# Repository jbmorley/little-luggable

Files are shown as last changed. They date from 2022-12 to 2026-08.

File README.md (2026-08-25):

# Little Luggable



Raspberry Pi Cyberdeck

## Overview

The Little Luggable is my take on a cyberdeck. It's built around the [Raspberry Pi 5](https://www.raspberrypi.com/products/raspberry-pi-5/) and the [Pelican 1150 Protector Case](https://www.peli.com/eu/en/product/cases/protector/1150). It includes a [fully-custom mechanical keyboard](/docs/keyboard) designed to perfectly fit the lid of the 1150.

Check out the [project page](https://little-luggable.jbmorley.co.uk) for more.

# License

Little Luggable is Copyright (c) 2022-2026 Jason Morley (see [COPYRIGHT](https://github.com/jbmorley/little-luggable/blob/main/COPYRIGHT)) and licensed under the [Creative Commons Attribution 4.0 International License](https://creativecommons.org/licenses/by/4.0/) (see [LICENSE](https://github.com/jbmorley/little-luggable/blob/main/LICENSE)). Unless otherwise stated, photographs are Copyright (c) 2026 [Mar Mizunaka](http://marmizunaka.com), and cannot be reproduced without permission.

The Little Luggable depends on the following separately licensed third-party libraries and components:

- [Keebio Components](https://github.com/keebio/keebio-components), MIT License
- [Keebio-Parts.pretty](https://github.com/keebio/Keebio-Parts.pretty), MIT License
- [marbastlib](https://github.com/ebastler/marbastlib), CERN Open Hardware Licence Version 2 – Permissive
- [Nabla](https://fonts.google.com/specimen/Nabla), SIL Open Font License 1.1
- [Recursive](https://fonts.google.com/specimen/Recursive), SIL Open Font License 1.1
- [ZMK](https://github.com/zmkfirmware/zmk), MIT License

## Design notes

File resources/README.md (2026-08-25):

# Resources

## Acknowledgements

The resources in this directory have been added for convenience and future reference and copyright remains with their respective owners. They are not covered by the broader license of this repository.

- [**12mm Switch**, David Giangola, GrabCAD](https://grabcad.com/library/12mm-switch-1) – 12mm-switch-1.snapshot.2.zip
- [**Tactile Switches 6mm THT**, Dmitry Levin, GrabCAD](https://grabcad.com/library/tactile-switches-6mm-tht-1) – tactile-switches-6mm-tht-1.snapshot.2.zip

- [**Display OLED128x32**, Danilo Clemente, GrabCAD](https://grabcad.com/library/display-oled128x32-1) – display-oled128x32-1.snapshot.4.zip

- [**Nabla**, The Nabla Project Authors, Google Fonts](https://fonts.google.com/specimen/Nabla) – fonts/ (SIL Open Font License 1.1, see fonts/Nabla-OFL.txt)

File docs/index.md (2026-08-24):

---
layout: page
---

<div class="header">
    <div class="appname">{{ site.title }}</div>
    <div class="model">
        <model-viewer id="model" alt="A 3D model of the Little Luggable cyberdeck: a Raspberry Pi 5 and a custom mechanical keyboard built into a Pelican 1150 case" auto-rotate-delay="0" rotation-per-second="45deg" camera-controls interaction-prompt="none" orientation="0 0 225deg" camera-orbit="0deg 54.736deg auto" src="models/little-luggable.glb" poster="/images/poster.webp" shadow-intensity="1" high-performance="low-power" disable-zoom disable-tap>
            
            <noscript>
                A 3D render of the Little Luggable cyberdeck: a Raspberry Pi 5 and a custom mechanical keyboard built into a Pelican 1150 case
            </noscript>
        </model-viewer>
    </div>
    <div class="tagline">{{ site.description }}</div>
</div>
<script type="module" src="/assets/js/model-home.js"></script>

The Little Luggable is my take on a cyberdeck. Built around the [Raspberry Pi](https://www.raspberrypi.com/products/raspberry-pi-5/) and the [Pelican 1150 Protector Case](https://www.peli.com/eu/en/product/cases/protector/1150), it features a [fully-custom mechanical keyboard](/docs/keyboard) designed to perfectly fit the lid of the 1150.
{: .center}

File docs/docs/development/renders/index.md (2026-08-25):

---
title: Renders
---

Generating renders for the documentation:

1. Render using Fusion with a white, solid color background, and no ground plane
2. Trim the resulting image using [mogrify](https://imagemagick.org/script/mogrify.php):
   ```bash
   mogrify -trim -bordercolor white -border 60 render.png
   ```

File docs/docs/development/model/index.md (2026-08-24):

---
title: Model
priority: -100
---

The website uses [`<model-viewer>`](https://modelviewer.dev) to display a 3D model of the Little Luggable.

# Model

There are a number of steps to generate a suitable model:

1. Export from Fusion as a USDZ file.
2. Import the USDZ file into Blender.
3. Manually update the materials as Fusion does a terrible job when exporting materials.
    1. Create the materials in Blender by importing and running `scripts/blender-materials.py`.
    2. Select each element in-turn, delete the original material, and assign the correct new material.
4. Export the model as a GLB file.
5. Optimize the model:
   ```sh
   scripts/optimize-model.sh \
       exports/little-luggable.glb \
       docs/models/little-luggable.glb
   ```

> [!IMPORTANT]
>
> Do not check the un-optimized model in; it's massive.

# Poster

`<model-viewer>` supports a 'poster' which is displayed while the model is loading, or if JavaScript is disabled. This is generated using `<model-viewer>` itself to ensure it displays identically and the transition from poster to model is seamless.

1. Serve the site and open the front page:
   ```sh
   cd docs
   bundle install
   bundle exec jekyll serve --watch
   ```
2. Run in the console, and move the download into `docs/images/`:
   ```js
   const v = document.querySelector('#model');
   const blob = await v.toBlob({ idealAspect: true, mimeType: 'image/webp', qualityArgument: 0.85 });
   Object.assign(document.createElement('a'), {
       href: URL.createObjectURL(blob),
       download: 'poster.webp',
   }).click();
   ```
4. Reference it from the element: `poster="/images/poster.webp"`.

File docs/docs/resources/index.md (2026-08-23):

---
title: Resources
priority: -100
---

# Video Guides

- [Making a Keyboard Macropad PCB (Kicad 6.0), Noah Kiser](https://www.youtube.com/watch?v=7O8xGd7Pd88)
- [Single Button Nice!Nano Keyboard, Ben Vallack](https://www.youtube.com/watch?v=vr8LkjsRqZs)
- [Make your own analog keyboard PCB (in Kicad) - Part 1 (Schematic), riskable](https://www.youtube.com/watch?v=TfKz_FbZWLQ)

# Parts

  - [Broaching Standoff](https://www.youtube.com/watch?v=TuJRveLrtYI)
  - [Broaching nuts and standoffs](https://www.inserco.eu/en/broaching-inserts-ipcbricbfhiscbr/)
  - [Solderable threaded inserts?](https://www.designdevelopmenttoday.com/new-products/fastening-assembly/fastening-assembly/product/21092287/keystone-electronics-corp-zero-height-threaded-inserts-for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)
  - [Keyswitch Kicad Library](https://github.com/perigoso/keyswitch-kicad-library)

# 3D Models

- [Pelicane Case 1150, GrabCAD](https://grabcad.com/library/pelicane-case-1150-1)
- [USB 3 Type A Female Connector, Free3D](https://free3d.com/3d-model/usb-3-type-a-female-connector-9922.html)

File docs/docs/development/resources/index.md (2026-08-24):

---
title: Resources
priority: -100
---

# Video Guides

- [Making a Keyboard Macropad PCB (Kicad 6.0), Noah Kiser](https://www.youtube.com/watch?v=7O8xGd7Pd88)
- [Single Button Nice!Nano Keyboard, Ben Vallack](https://www.youtube.com/watch?v=vr8LkjsRqZs)
- [Make your own analog keyboard PCB (in Kicad) - Part 1 (Schematic), riskable](https://www.youtube.com/watch?v=TfKz_FbZWLQ)

# Manufacture

- [Recommended Tapping Drill and Clearance Hole Sizes](https://international.optimas.com/technical-resources/tapping-sizes/)

# Dimensions

- [Keystone cutout](https://www.phoenixcontact.com/en-pc/products/rj45-socket-insert-cuc-k-j1zni-s-r4idc8-1419021)

  

# Parts

  - [Broaching Standoff](https://www.youtube.com/watch?v=TuJRveLrtYI)
  - [Broaching nuts and standoffs](https://www.inserco.eu/en/broaching-inserts-ipcbricbfhiscbr/)
  - [Solderable threaded inserts?](https://www.designdevelopmenttoday.com/new-products/fastening-assembly/fastening-assembly/product/21092287/keystone-electronics-corp-zero-height-threaded-inserts-for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)
  - [Keyswitch Kicad Library](https://github.com/perigoso/keyswitch-kicad-library)

# 3D Models

- [Pelicane Case 1150, GrabCAD](https://grabcad.com/library/pelicane-case-1150-1)
- [USB 3 Type A Female Connector, Free3D](https://free3d.com/3d-model/usb-3-type-a-female-connector-9922.html)

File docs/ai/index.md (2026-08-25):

---
title: AI
---

# Generation

No AI was used in the creation of the Little Luggable hardware designs, and all photographs, images, and text used in the project, and on this website are human-authored.

Some AI tooling was used to generate support scripts for this website. This code has been reviewed thoroughly and its use is limited in scope. Source code created using AI is clearly marked and no copyright or license is asserted for these files.

## docs/assets/js/

- [`model-home.js`](https://github.com/jbmorley/little-luggable/blob/main/docs/assets/js/model-home.js)---JavaScript to animate the 3D model transition back to its home position

## scripts/

- [`blender-materials.py`](https://github.com/jbmorley/little-luggable/blob/main/scripts/blender-materials.py)---Python script to create Blender materials
- [`optimize-model.sh`](https://github.com/jbmorley/little-luggable/blob/main/scripts/optimize-model.sh)---Bash script calling `gltf-transform` to simplify GLB models
- [`recolor-nabla.py`](https://github.com/jbmorley/little-luggable/blob/main/scripts/recolor-nabla.py)---Python script to apply a color palettes to WOFF SVG fonts
- [`resize-images.sh`](https://github.com/jbmorley/little-luggable/blob/main/scripts/resize-images.sh)---Bash script to generate multiple sizes for images hosted on this website

# Tools

Little Luggable was created using [Autodesk Fusion](https://www.autodesk.com/trust/trusted-ai/ai-transparency-cards), on operating systems (macOS and Linux) known to be developed in part using AI. [Claude](https://claude.com) was used for research and as a search proxy.

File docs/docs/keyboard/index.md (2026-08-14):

---
title: Keyboard
---

The Little Keyboard is a custom 64-key keyboard that I created with the very specific goal of deviating as little as possible from a standard keyboard layout---it essentially doubles up the keys on the right-hand side of the keyboard by using the 'raise' modifier. Emoji keys are mapped using the 'lower' modifier, entered as unicode character codes using macros.



> [!TIP]
>
> This design was created using [Keyboard Layout Editor](http://www.keyboard-layout-editor.com) and the JSON can be found in the `keyboard` directory. It's best to use Chrome as, at the time of writing, PNG export doesn't work in Safari.

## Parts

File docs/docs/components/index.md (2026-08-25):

---
title: Components
---

The Little Luggable consists of two distinct components:

- [Compute](compute)---the Raspberry Pi, display, and UPS power board
- [Keyboard](keyboard)---the Bluetooth keyboard and battery

These both comprise a collection of 3D printed, milled, and laser-cut parts, as well as a number of off-the-shelf components.

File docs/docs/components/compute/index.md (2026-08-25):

---
title: Compute
priority: 90
---



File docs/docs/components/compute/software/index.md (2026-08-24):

---
title: Software
---

# Operating System

The Little Luggable uses a Raspberry Pi, so you can use any operating system compatible with this incredibly versatile device. Personally, I am currently using Ubuntu Resolute 26.04.

# RTC

The Raspberry Pi 5 supports a [rechargeable real-time clock battery](https://www.raspberrypi.com/products/rtc-battery/) which is crucial if you're going to use it in a battery powered device like the Little Luggable.

In order to ensure the battery recharges, you'll need to add the following to your `config.txt`:

```plaintext
dtparam=rtc_bbat_vchg=3000000
```

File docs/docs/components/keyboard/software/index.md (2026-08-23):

---
title: Software
priority: 90
---

## Shortcuts

### Bluetooth

The keyboard can be paired with multiple devices.

- **Lower + Esc 1, 2, 3, 4** – select Bluetooth device
- **Lower + F5** – clear the current Bluetooth pairing

### Symbols

The keyboard is designed to be as close to a regular staggered key layout as possible. Since it's narrower than a standard keyboard, symbols typically to the right of the keyboard share space with the right-side letters and are accessible using the **Raise** modifier.

### Emoji

Dedicated emoji keys (achieved by unicode modifier key sequence macros) are available under many letters using the **Lower** modifier. This is experimental and the mapping is likely to evolve over time (I'd like to find room for  🥹, 🤯, and 👍 at the very least).

- **QUERTY**
  - **Lower + Q** – 🤔
  - **Lower + W** – 🧐
  - **Lower + E** – 😬
  - **Lower + R** – 🥲
  - **Lower + T** – 🙃
  - **Lower + Y** – 🫠
  - **Lower + U** – 😭
  - **Lower + I** – 🥰
  - **Lower + O** – 😘
  - **Lower + P** – 🤗
- **ASDF**
  - **Lower + A** – 🤞
  - **Lower + S** – 👆
  - **Lower + D** – 👌
- **ZXCV**
  - **Lower + Z** – ❤️
  - **Lower + X** – 🎉
  - **Lower + C** – 👀

### Firmware Version

You can trigger a macro to type in the current firmware version and build number using **Lower + Raise + A**.

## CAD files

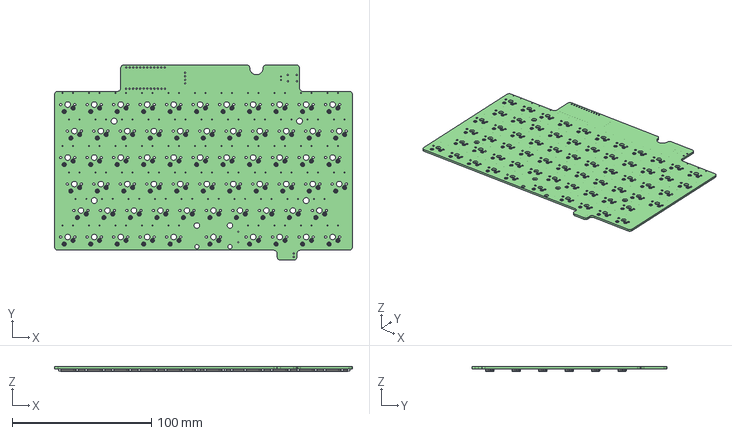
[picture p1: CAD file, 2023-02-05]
keyboard/keyboard.step
214.3 x 140.5 x 3.47 mm
keyboard PCB

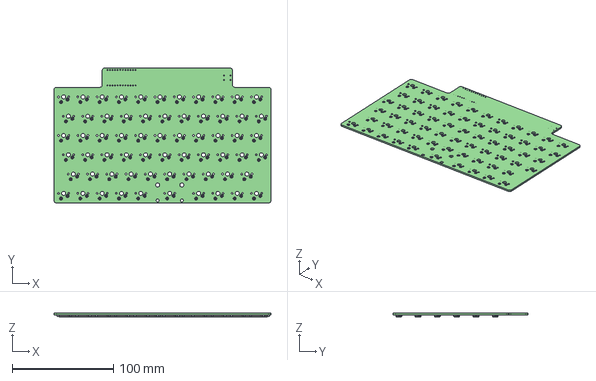
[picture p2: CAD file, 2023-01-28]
keyboard/pcb/keyboard.step
214.3 x 133.3 x 3.47 mm
keyboard PCB

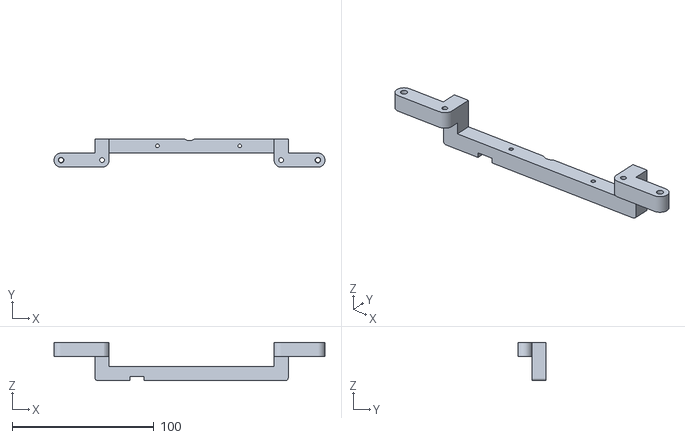
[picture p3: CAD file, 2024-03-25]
manufacture/bracket-top.stl
191.0 x 20.0 x 27.0

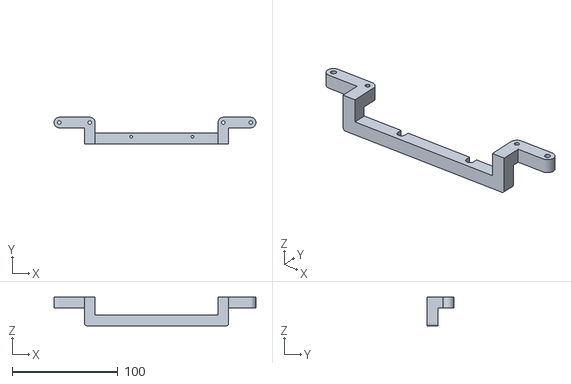
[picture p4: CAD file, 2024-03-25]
manufacture/bracket-bottom.stl
191.0 x 25.1 x 27.0

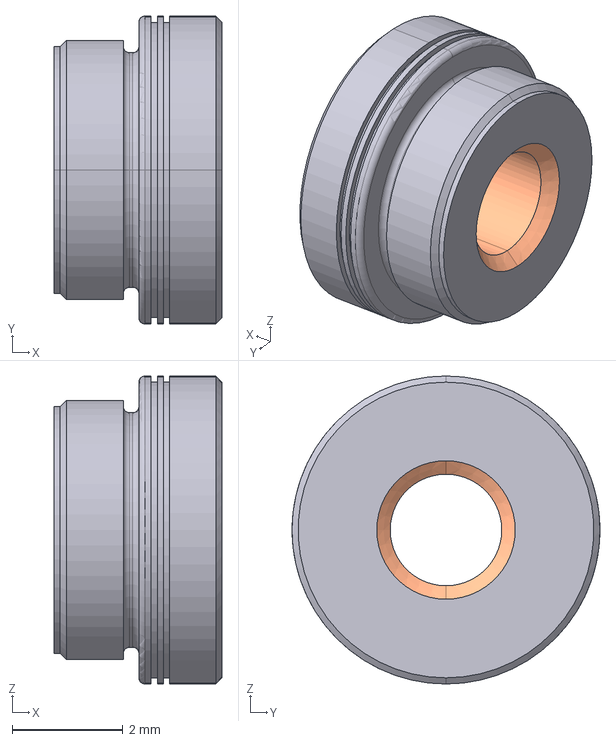
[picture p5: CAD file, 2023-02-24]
resources/KF2-M2.5-ET-Zygology-3D-02-05-2023.stp
3.03 x 5.56 x 5.56 mm

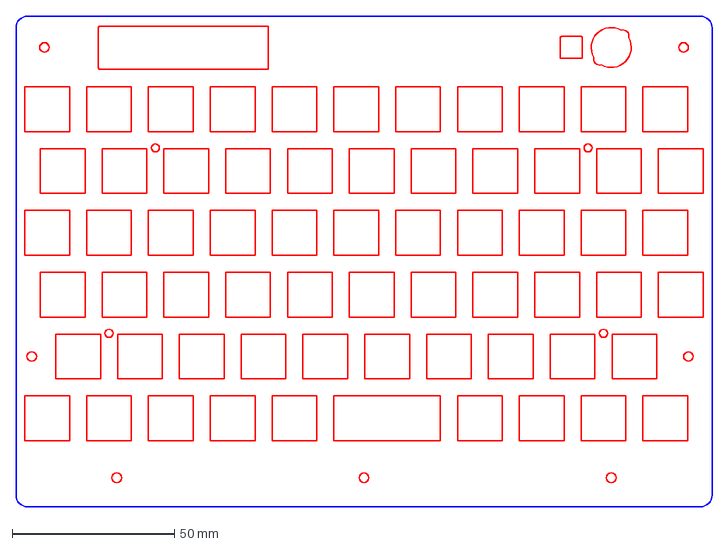
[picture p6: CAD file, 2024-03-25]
manufacture/keyboard-mounting-plate-kerf-adjusted-0.2.dxf
214.5 x 151.2 mm

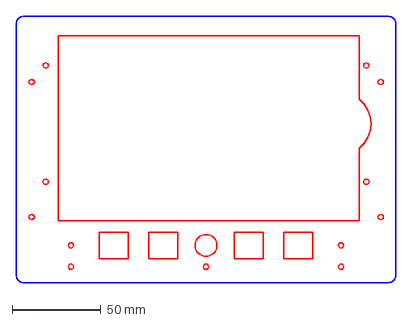
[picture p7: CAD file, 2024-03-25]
manufacture/screen-fascia-bottom-kerf-adjusted-0.2.dxf
214.2 x 150.2 mm

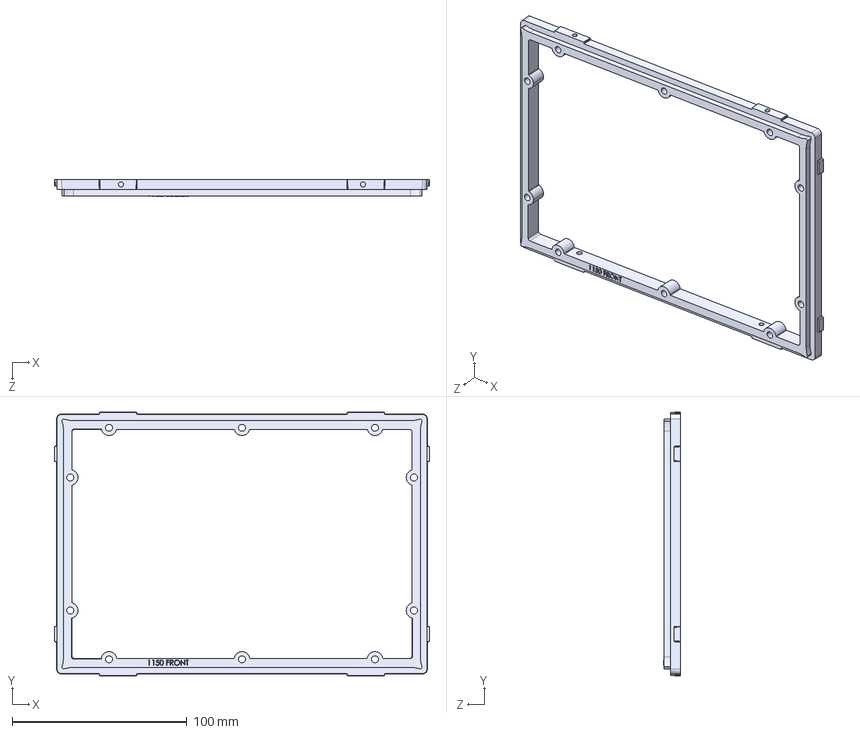
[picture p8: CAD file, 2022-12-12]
resources/1153-946-110.STEP
214.9 x 151.2 x 9.65 mm

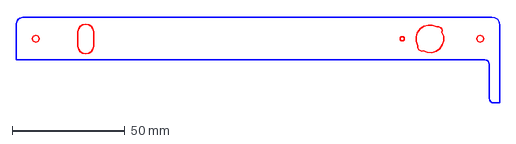
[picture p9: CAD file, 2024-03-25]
manufacture/keyboard-fascia-top-kerf-adjusted-0.2.dxf
214.5 x 38.1 mm

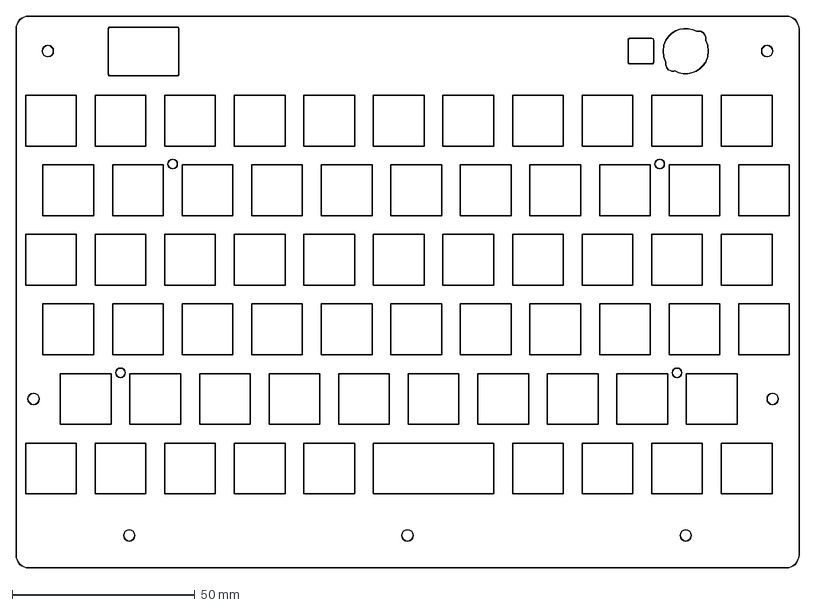
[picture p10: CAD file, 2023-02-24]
manufacture/keyboard-mounting-plate-kerf-adjusted-0.1.dxf
214.4 x 151.1 mm

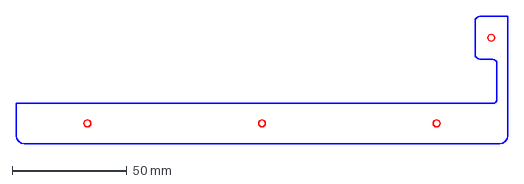
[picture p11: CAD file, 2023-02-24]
manufacture/keyboard-fascia-bottom-kerf-adjusted-0.2.dxf
214.5 x 55.7 mm

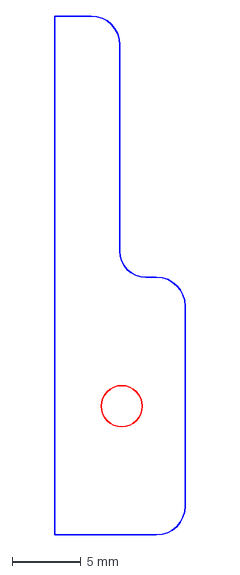
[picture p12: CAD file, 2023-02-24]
manufacture/keyboard-fascia-left-kerf-adjusted-0.2.dxf
9.50 x 37.8 mm

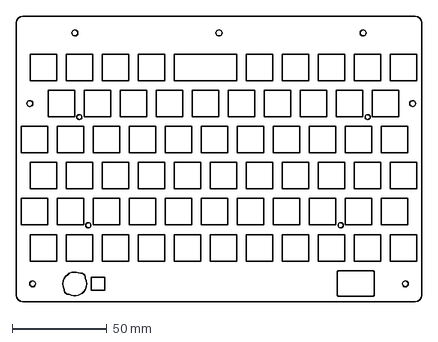
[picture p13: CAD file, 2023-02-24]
manufacture/keyboard-mounting-plate.dxf
214.3 x 151.0 mm

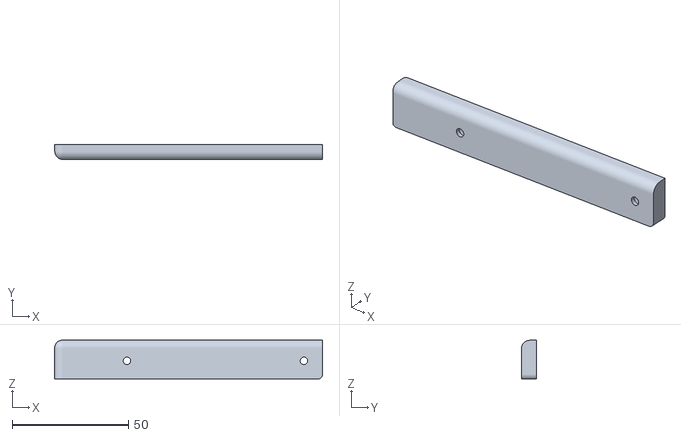
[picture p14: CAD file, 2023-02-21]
manufacture/keyboard-mounting-bracket-bottom-left.stl
115.4 x 6.47 x 16.8

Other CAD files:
manufacture/keyboard-switch-collar.stl
manufacture/keyboard-usb-port-collar.stl
manufacture/keyboard-mounting-bracket-bottom-right.stl
manufacture/screen-switch-collar.stl
manufacture/back.dxf
manufacture/keyboard-mounting-bracket-top-left.stl
manufacture/keyboard-mounting-bracket-top-right.stl
manufacture/keyboard-pcb.dxf
resources/91200A222_18-8 Stainless Steel Pan Head Slotted Screws.STEP
resources/93070A070_Alloy Steel Low-Profile Socket Head Screw.STEP

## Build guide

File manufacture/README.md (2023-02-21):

# Manufacture

## Settings

Settings for the [Makespace](https://makespace.org) laser cutters[^laser]:

[^laser]: These are for my own personal reference; you'll almost certainly want to do a few test cuts with your own laser cutter to dial in the correct settings.

- Jaws
  - 3mm acrylic
    - Speed = 10
    - Power = 85
    - Corner Power = 80

  - 1.5mm acrylic
    - Speed = 10
    - Power = 55
    - Corner Power = 55

- Betsy
  - 3mm acrylic
    - Speed = 10
    - Power = 90
    - Corner Power = 85

  - 1.5mm acrylic
    - Speed = 10
    - Power = 55
    - Corner Power = 55

N.B. When cutting 1.5mm acrylic, the kerfing[^kerf] seems to be about 0.2mm so dimensions need to be adjusted for high-tolerance parts like the keyboard mounting plate. For example, I found I needed to adjust the 14mm key-switch cutouts to be **13.8mm** to ensure the switches clip securely in place. I'm using the [DXF for Laser](https://apps.autodesk.com/FUSION/en/Detail/Index?id=7634902334100976871&appLang=en&os=Win64&autostart=true) plugin for Fusion 360 to automatically export kerf-adjusted parts.

[^kerf]: I'm measuring kerfing as the full width of the cut, meaning a 0.2mm kerf will shrink parts on each side of a cut by 0.1mm. I believe this is the correct definition of 'kerf' but wanted to clarify just in case my understanding was incorrect.

## Exports

Export as DXF using Adobe Illustrator for AutoCAD 2018:

Screenshot of Adobe Illustrator DXF export dialog

## Changes

### v1

### v2

### v3

- Add the power socket to the fascia and mounting bracket

### v4

- Initial prototype of the keyboard fascia and mounting plate

### v5

- Update the keyboard fascia to wrap around the keys
- Add power switch, reset switch, and USB-C port to the keyboard fascia
- Add mounting holes to the keyboard mounting plate
- Add collar for the keyboard latching switch
- Add keyboard PCB silhouette for fit testing

### v6

- Update the keyboard PCB silhouette to reposition the nice!nano and include the holes for the broaching nuts, and through-holes for the battery and power switch

### v7

- Update the keyboard fascia and mounting plate to [exactly] match the new PCB
- Add the keyboard mounting brackets

### v8

- Increase the M3 and M2.5 hole sizes across the screen and keyboard components (to 3.2mm and 2.7mm respectively)
- Increase the switch cutout diameter from 12mm to 12.5mm
- Increase the switch collar inner diameter to 12.25 and export an STL file for 3D printing
  - Add a screen switch collar (identical to the keyboard switch collar)
- Add a collar for the 90 degree keyboard USB-C port
- Update the bottom-left and bottom-right keyboard mounting brackets to actually centre the mounting holes on the case (and not the bottom row of keys)
- Add 0.2mm kerf-adjusted exports of the keyboard fascias and mounting plate

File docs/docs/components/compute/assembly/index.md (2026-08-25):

---
title: Assembly
priority: 90
---

# Parts

## Off-The-Shelf

| **Part** | **Quantity** |
| --- | --- |
| [Raspberry Pi 4 Model B](https://www.raspberrypi.com/products/raspberry-pi-4-model-b/) | 1 |
| [Raspberry Pi Touch Display](https://www.raspberrypi.com/products/raspberry-pi-touch-display/) | 1 |
| [PiJuice HAT](https://uk.pi-supply.com/products/pijuice-standard) | 1 |
| [PiJuice 12000mAh Battery](https://uk.pi-supply.com/products/pijuice-12000mah-battery) | 1 |
| [Pelican 1150 Protector Case](https://peliproducts.co.uk/products/1150-protector-case) | 1 |
| [Pelican 1150 Panel Frame](https://peliproducts.co.uk/products/1150-panel-frame) | 1 |
| [M3 Washer](https://www.amazon.co.uk/3mm-Flat-Washer-Form-Stainless/dp/B08TDPSBBY) | 4 |
| [M3 Spacer, 3mm](https://www.amazon.co.uk/dp/B0BHJP3KJP) | 6 |
| [Raspberry Pi Standoff Set, 11mm](https://thepihut.com/products/raspberry-pi-standoff-set-11mm) | 1 |
| [USB-C Keystone Jack](https://www.amazon.co.uk/dp/B07Z947FRN) | 2 |
| [RJ45 Keystone Jack](https://www.amazon.co.uk/dp/B07KMQPC3L) | 1 |
| [USB-A Keystone Cable](https://www.amazon.co.uk/dp/B09B3YC29M) | 1 |

## Custom

- Fascia, 3mm Acrylic, Laser Cut

  

- Mounting Plate, 1mm Aluminium, Laser Cut


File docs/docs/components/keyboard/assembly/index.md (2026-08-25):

---
title: Assembly
priority: 100
---

# Parts



## Off-The-Shelf

| **Part** | **Quantity** |
| --- | --- |
| [nice!nano](https://nicekeyboards.com/nice-nano/) | 1 |
| [Rama Works GRID Set A Keycaps, Kuro](https://ramaworks.store/collections/grid/products/grid-set-a?variant=16185106235435) | 46 |
| [Rama Works GRID Set B Keycaps, Noct](https://ramaworks.store/collections/grid/products/grid-set-b?variant=31922049286222) | 18 |
| [M3 Spacer, 5mm](https://www.amazon.co.uk/dp/B0BHKJG3ST) | 7 |
| 6mm tactile push button | 1 |
| [Kailh MX Hotswap Sockets](https://mechboards.co.uk/products/kailh-hotswap-sockets) | 64 |
| [3.7V 90mAh Lithium Polymer Battery](https://www.ebay.co.uk/itm/195234783901) | 1 |
| [M3 Knurled Insert Nuts, 0.5mm](https://www.amazon.co.uk/dp/B09MCX5HN5) | 5 |
| [1N4148 Throughhole Diode](https://mechboards.co.uk/products/throughhole-diodes) | 64 |
| [12mm Latching Push Button Switch](https://www.amazon.co.uk/dp/B08L484J7W) | 1 |
| M3 Low-Profile Screws, ?mm | 7 |
| M3 Nut | 2 |
| [90 Degree USB-C Adapter](https://www.amazon.co.uk/dp/B078MX7L84) | 1 |
| M2.5 Screws | 4 |
| Broaching Nuts | 4 |
| M2.5 Spacers, 3mm | 4 |
| Female Dupont Connector | 4 |
| [Cherry MX Red Switches](https://mechboards.co.uk/products/cherry-mx-red) | 64 |
| 90 Degree Headers, 2 wide | 2 |

## Custom

- [Power Switch Collar, 3mm Acrylic, Laser Cut](manufacture/v7/switch-collar.dxf)

- Fascia, 3mm Acrylic, Laser Cut

  - [Top](manufacture/v7/keyboard-fascia-top.dxf)
  - [Left](manufacture/v7/keyboard-fascia-left.dxf)
  - [Bottom](manufacture/v7/keyboard-fascia-bottom.dxf)
    

- [Mounting Plate, 1.5mm Aluminium, Laser Cut](manufacture/v7/keyboard-mounting-plate.dxf)
  

- PCB
  

- Mounting Brackets, 3D Printed


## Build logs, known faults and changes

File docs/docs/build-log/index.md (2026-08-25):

---
title: Build Log
priority: 100
---

The Little Luggable is an ever-evolving project. The initial build took about 6 months elapsed, starting in December 2022, through to summer 2023. I originally used a Raspberry Pi 4 and have since upgraded to a 5.

The initial goal was to build a near off-the-shelf device and use a cheap pre-made keyboard---something to give me an excuse to visit Makespace, my local maker space, without requiring me to take on yet another large project. Needless to say, those lofty goals did not last long.





While using a cheap Bluetooth keyboard, it flexed in the 3D printed bracket and was uncomfortably springy while typing. I set about designing my own keyboard almost immediately.















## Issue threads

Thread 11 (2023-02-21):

Correct the keystone cutout dimensions

jbmorley, 2023-02-21:
Right now the dimensions of the keystone cutouts are wrong; the fascia cutouts almost certainly only work because of the laser kerfing which I'd not accounted for when cutting the fascia (and would like to be able to correctly account for in the future), and the mounting plate cutouts are too narrow making it very hard to clip the keystones in place. I've added a diagram showing one manufacturer's expected tolerance for this plate to the readme (https://github.com/jbmorley/little-luggable#useful-references) and it seems like all dimensions are a little small; it'd probably be best to pick something in the middle of the range.

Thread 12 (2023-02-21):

The OLED display connector is in the wrong place

jbmorley, 2023-02-21:
The current connector position centres the display on the top 'tab' of the PCB, instead of centring it on the full horizontal width. This means it looks quite misaligned when the keyboard is assembled.

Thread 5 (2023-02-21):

The keyboard fascia is too close to the keys

jbmorley, 2023-02-21:
It seems like the laser kerf was allowing me to get away with a design that was a little too close to the keys. The clearance should be increased slightly to allow for kerf-aware exports to work.

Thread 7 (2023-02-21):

It's difficult to plug the battery and power switch into the keyboard PCB

jbmorley, 2023-02-21:
Right now the headers for the battery and power switch are sandwiched between the switch mounting plate and the PCB. Due to the height of the dupont connectors, they need to be on the top of the PCB, but it might be helpful to have the header pins extend beyond the edge of the board (bigger cutouts?) to make it easier to connect them from the bottom.

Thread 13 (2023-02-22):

Tracks are too close to the broaching nut mounting holes

jbmorley, 2023-02-22:
A couple of the PCB tracks run very close to the mounting holes for the broaching nuts. I've not had any problems with them yet, but these should be rerouted to give a little more clearance.

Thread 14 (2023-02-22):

Explore better ways to attach the non-structural keyboard fascia components

jbmorley, 2023-02-22:
The left and right-most parts of the keyboard fascia are non-structural; they just fill in gaps created by the key stagger. These are difficult to attach as they need to be mounted to the key mounting plate prior to attaching the PCB. It might be better to add some aligned holes in the PCB so these can be added after everything else has been assembled. Perhaps broaching nuts could be used here too.

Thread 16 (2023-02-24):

Find a shorter power switch for the keyboard

jbmorley, 2023-02-24:
How about something like this?

https://www.mouser.co.uk/datasheet/2/57/Bulgin_12mm_Switches-1661249.pdf
https://www.mouser.co.uk/ProductDetail/Bulgin/MAV0120-3D2RD024?qs=PqoDHHvF64%252BxWa720U1gHw%3D%3D

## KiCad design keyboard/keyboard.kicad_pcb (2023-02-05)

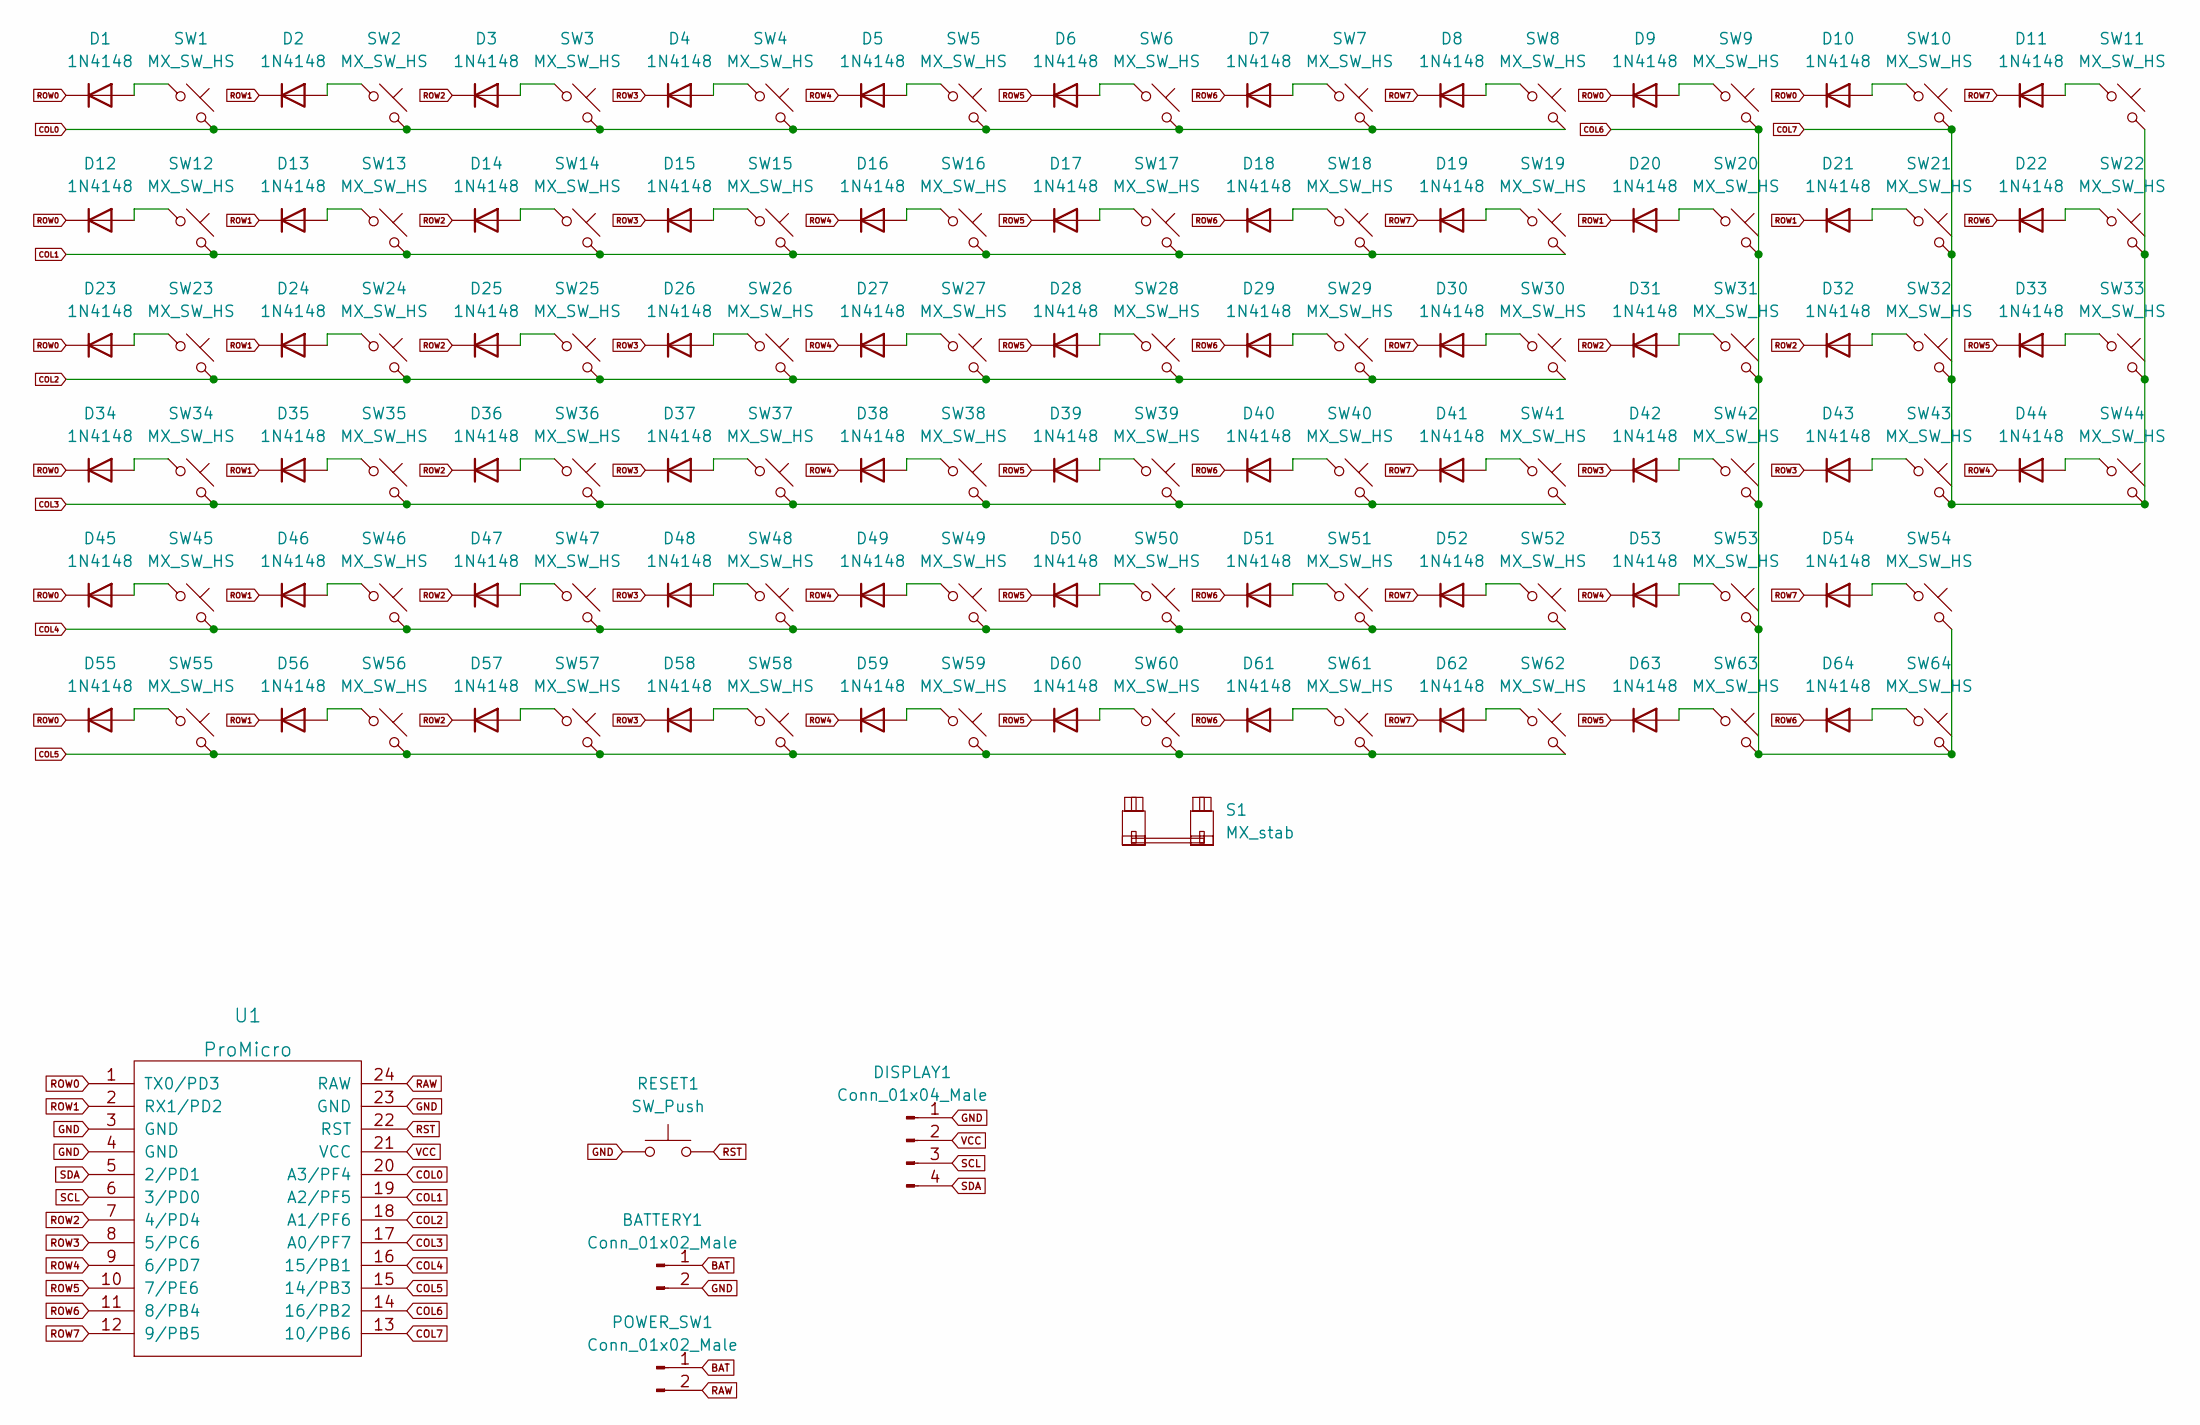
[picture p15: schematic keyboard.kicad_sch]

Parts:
BATTERY1: Conn_01x02_Male; PinHeader_1x02_P2.54mm_Vertical
D1, D2, D3, D4, D5, D6, D7, D8, D9, D10, D11, D12, D13, D14, D15, D16, D17, D18, D19, D20, D21, D22, D23, D24, D25, D26, D27, D28, D29, D30, D31, D32, D33, D34, D35, D36, D37, D38, D39, D40, D41, D42, D43, D44, D45, D46, D47, D48, D49, D50, D51, D52, D53, D54, D55, D56, D57, D58, D59, D60, D61, D62, D63, D64: 1N4148; D_DO-35_SOD27_P7.62mm_Horizontal
DISPLAY1: Conn_01x04_Male; PinHeader_1x04_P2.54mm_Vertical
POWER_SW1: Conn_01x02_Male; PinHeader_1x02_P2.54mm_Horizontal
RESET1: SW_Push; SW_PUSH_6mm_H13mm
S1: MX_stab; STAB_MX_P_2u
SW1, SW2, SW3, SW4, SW5, SW6, SW7, SW8, SW9, SW10, SW11, SW12, SW13, SW14, SW15, SW16, SW17, SW18, SW19, SW20, SW21, SW22, SW23, SW24, SW25, SW26, SW27, SW28, SW29, SW30, SW31, SW32, SW33, SW34, SW35, SW36, SW37, SW38, SW39, SW40, SW41, SW42, SW43, SW44, SW45, SW46, SW47, SW48, SW49, SW50, SW51, SW52, SW53, SW54, SW55, SW56, SW57, SW58, SW59, SW60, SW61, SW62, SW63, SW64: MX_SW_HS; SW_MX_HS_1u
U1: ProMicro; ArduinoProMicro

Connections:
BAT: BATTERY1.1, POWER_SW1.1; also elsewhere on the board
COL0: SW1.2, SW2.2, SW3.2, SW4.2, SW5.2, SW6.2, SW7.2, SW8.2, U1.20 (A3/PF4)
COL1: SW12.2, SW13.2, SW14.2, SW15.2, SW16.2, SW17.2, SW18.2, SW19.2, U1.19 (A2/PF5)
COL2: SW23.2, SW24.2, SW25.2, SW26.2, SW27.2, SW28.2, SW29.2, SW30.2, U1.18 (A1/PF6)
COL3: SW34.2, SW35.2, SW36.2, SW37.2, SW38.2, SW39.2, SW40.2, SW41.2, U1.17 (A0/PF7)
COL4: SW45.2, SW46.2, SW47.2, SW48.2, SW49.2, SW50.2, SW51.2, SW52.2, U1.16 (15/PB1)
COL5: SW55.2, SW56.2, SW57.2, SW58.2, SW59.2, SW60.2, SW61.2, SW62.2, U1.15 (14/PB3)
COL6: SW9.2, SW20.2, SW31.2, SW42.2, SW53.2, SW54.2, SW63.2, SW64.2, U1.14 (16/PB2)
COL7: SW10.2, SW11.2, SW21.2, SW22.2, SW32.2, SW33.2, SW43.2, SW44.2, U1.13 (10/PB6)
GND: BATTERY1.2, DISPLAY1.1, RESET1.1, U1.3 (GND), U1.4 (GND), U1.23 (GND); also elsewhere on the board
unnamed: D1.2 (A), SW1.1
unnamed: D2.2 (A), SW2.1
unnamed: D3.2 (A), SW3.1
unnamed: D4.2 (A), SW4.1
unnamed: D5.2 (A), SW5.1
unnamed: D6.2 (A), SW6.1
unnamed: D7.2 (A), SW7.1
unnamed: D8.2 (A), SW8.1
unnamed: D9.2 (A), SW9.1
unnamed: D10.2 (A), SW10.1
unnamed: D11.2 (A), SW11.1
unnamed: D12.2 (A), SW12.1
unnamed: D13.2 (A), SW13.1
unnamed: D14.2 (A), SW14.1
unnamed: D15.2 (A), SW15.1
unnamed: D16.2 (A), SW16.1
unnamed: D17.2 (A), SW17.1
unnamed: D18.2 (A), SW18.1
unnamed: D19.2 (A), SW19.1
unnamed: D20.2 (A), SW20.1
unnamed: D21.2 (A), SW21.1
unnamed: D22.2 (A), SW22.1
unnamed: D23.2 (A), SW23.1
unnamed: D24.2 (A), SW24.1
unnamed: D25.2 (A), SW25.1
unnamed: D26.2 (A), SW26.1
unnamed: D27.2 (A), SW27.1
unnamed: D28.2 (A), SW28.1
unnamed: D29.2 (A), SW29.1
unnamed: D30.2 (A), SW30.1
unnamed: D31.2 (A), SW31.1
unnamed: D32.2 (A), SW32.1
unnamed: D33.2 (A), SW33.1
unnamed: D34.2 (A), SW34.1
unnamed: D35.2 (A), SW35.1
unnamed: D36.2 (A), SW36.1
unnamed: D37.2 (A), SW37.1
unnamed: D38.2 (A), SW38.1
unnamed: D39.2 (A), SW39.1
unnamed: D40.2 (A), SW40.1
unnamed: D41.2 (A), SW41.1
unnamed: D42.2 (A), SW42.1
unnamed: D43.2 (A), SW43.1
unnamed: D44.2 (A), SW44.1
unnamed: D45.2 (A), SW45.1
unnamed: D46.2 (A), SW46.1
unnamed: D47.2 (A), SW47.1
unnamed: D48.2 (A), SW48.1
unnamed: D49.2 (A), SW49.1
unnamed: D50.2 (A), SW50.1
unnamed: D51.2 (A), SW51.1
unnamed: D52.2 (A), SW52.1
unnamed: D53.2 (A), SW53.1
unnamed: D54.2 (A), SW54.1
unnamed: D55.2 (A), SW55.1
unnamed: D56.2 (A), SW56.1
unnamed: D57.2 (A), SW57.1
unnamed: D58.2 (A), SW58.1
unnamed: D59.2 (A), SW59.1
unnamed: D60.2 (A), SW60.1
unnamed: D61.2 (A), SW61.1
unnamed: D62.2 (A), SW62.1
unnamed: D63.2 (A), SW63.1
unnamed: D64.2 (A), SW64.1
RAW: POWER_SW1.2, U1.24 (RAW); also elsewhere on the board
ROW0: D1.1 (K), D9.1 (K), D10.1 (K), D12.1 (K), D23.1 (K), D34.1 (K), D45.1 (K), D55.1 (K), U1.1 (TX0/PD3)
ROW1: D2.1 (K), D13.1 (K), D20.1 (K), D21.1 (K), D24.1 (K), D35.1 (K), D46.1 (K), D56.1 (K), U1.2 (RX1/PD2)
ROW2: D3.1 (K), D14.1 (K), D25.1 (K), D31.1 (K), D32.1 (K), D36.1 (K), D47.1 (K), D57.1 (K), U1.7 (4/PD4)
ROW3: D4.1 (K), D15.1 (K), D26.1 (K), D37.1 (K), D42.1 (K), D43.1 (K), D48.1 (K), D58.1 (K), U1.8 (5/PC6)
ROW4: D5.1 (K), D16.1 (K), D27.1 (K), D38.1 (K), D44.1 (K), D49.1 (K), D53.1 (K), D59.1 (K), U1.9 (6/PD7)
ROW5: D6.1 (K), D17.1 (K), D28.1 (K), D33.1 (K), D39.1 (K), D50.1 (K), D60.1 (K), D63.1 (K), U1.10 (7/PE6)
ROW6: D7.1 (K), D18.1 (K), D22.1 (K), D29.1 (K), D40.1 (K), D51.1 (K), D61.1 (K), D64.1 (K), U1.11 (8/PB4)
ROW7: D8.1 (K), D11.1 (K), D19.1 (K), D30.1 (K), D41.1 (K), D52.1 (K), D54.1 (K), D62.1 (K), U1.12 (9/PB5)
RST: RESET1.2, U1.22 (RST); also elsewhere on the board
SCL: DISPLAY1.3, U1.6 (3/PD0); also elsewhere on the board
SDA: DISPLAY1.4, U1.5 (2/PD1); also elsewhere on the board
VCC: DISPLAY1.2, U1.21 (VCC); also elsewhere on the board

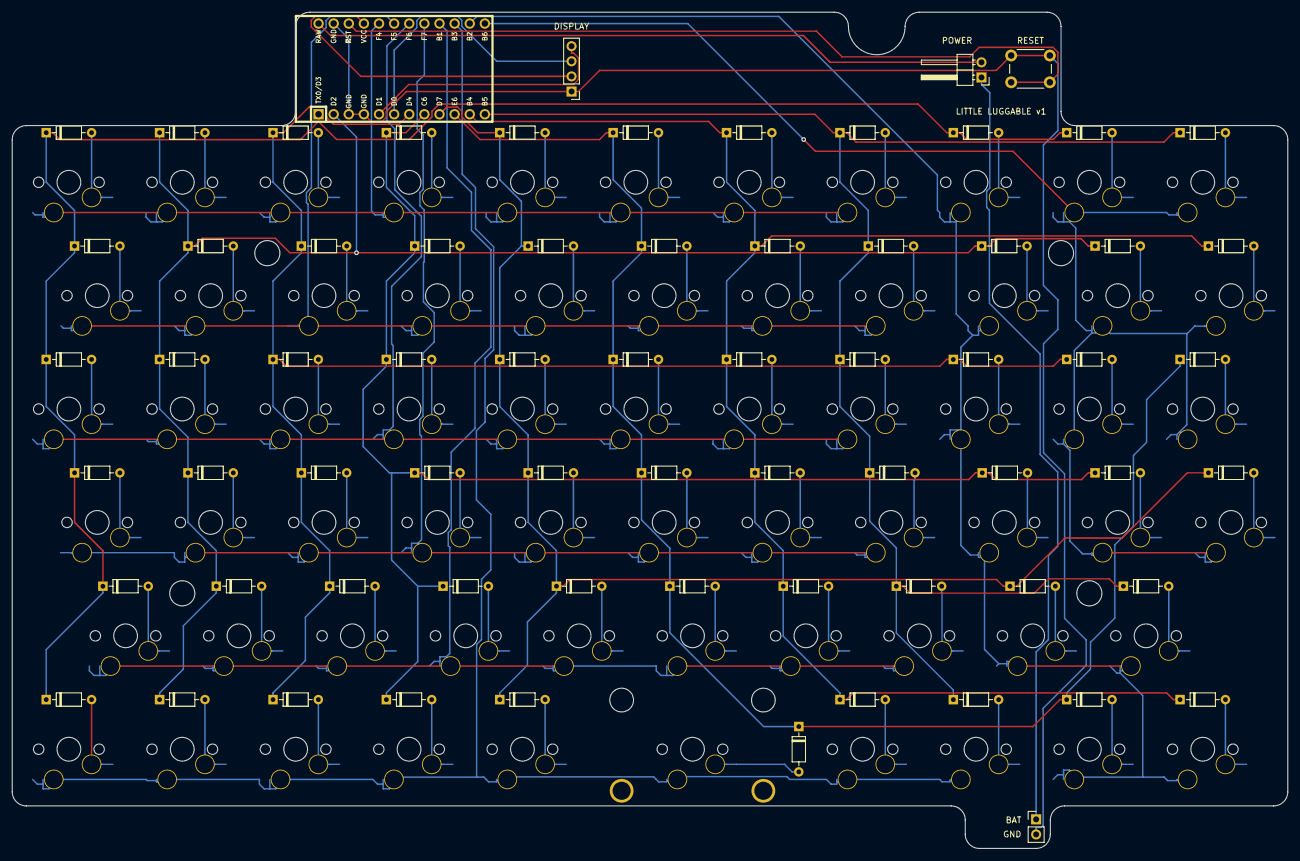
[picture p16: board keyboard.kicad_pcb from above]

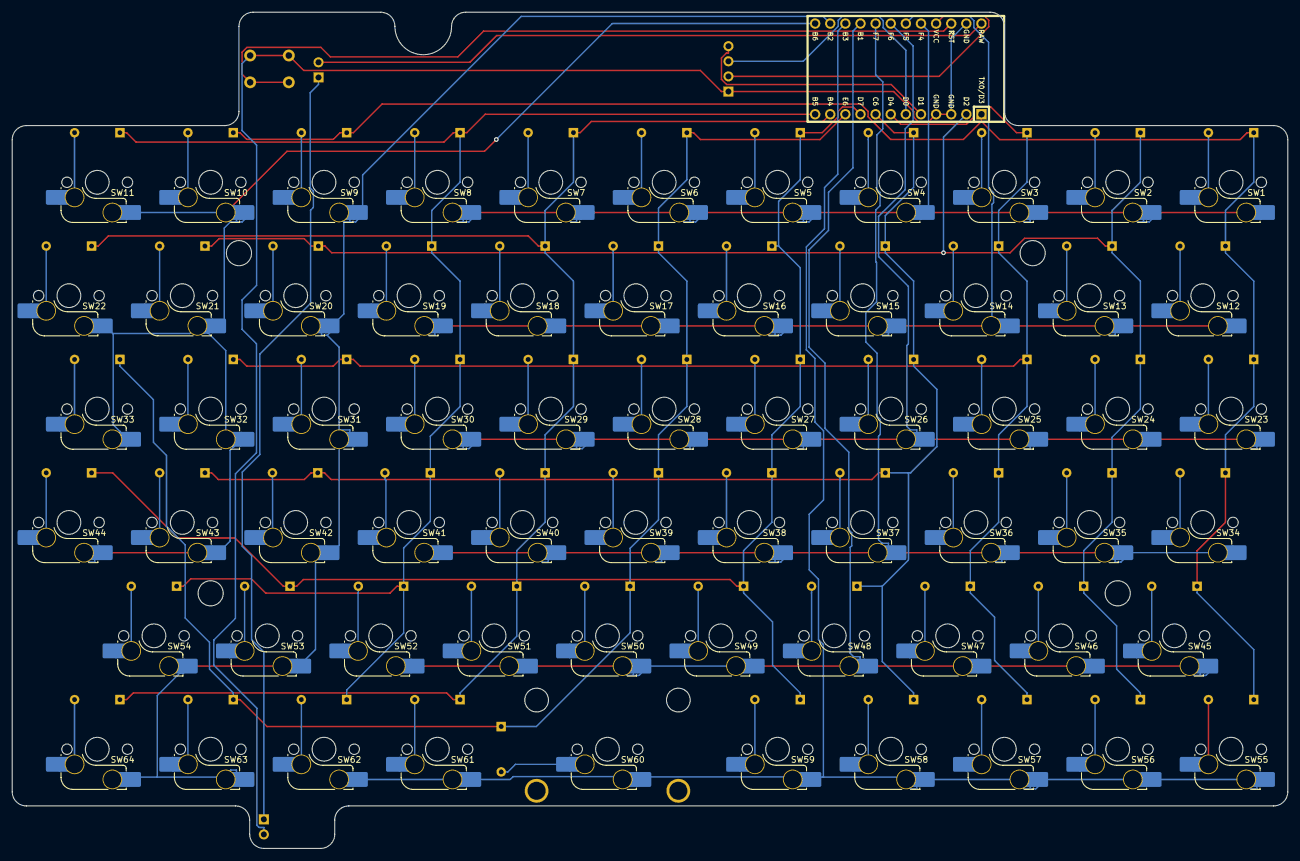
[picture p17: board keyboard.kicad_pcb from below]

Board: 2 copper layers, 214.3 x 140.5 mm, 134 parts (64 on the bottom side), 87 nets.

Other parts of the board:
DISPLAY: Conn_01x04_Male; PinHeader_1x04_P2.54mm_Vertical
POWER: Conn_01x02_Male; PinHeader_1x02_P2.54mm_Horizontal
RESET: SW_Push; SW_PUSH_6mm_H13mm

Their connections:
BAT: POWER.1; also elsewhere on the board
GND: DISPLAY.1, RESET.1; also elsewhere on the board
RAW: POWER.2; also elsewhere on the board
RST: RESET.2; also elsewhere on the board
SCL: DISPLAY.3; also elsewhere on the board
SDA: DISPLAY.4; also elsewhere on the board
VCC: DISPLAY.2; also elsewhere on the board

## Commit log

2022-12-12 Add initial design resources
    [1153-946-110.STEP]
2022-12-16 Add the v2 exports
    [back.dxf, front.dxf]
2022-12-16 Add the v1 export
    [back.dxf, front.dxf, spacer.dxf]
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2023-01-06 Add updated manufacture files with switch mounting
    [back.dxf, front.dxf]
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2023-01-25 Add empty keyboard project
    [keyboard.kicad_pcb, keyboard.kicad_sch]
2023-01-25 Initial work to add the keys to the keyboard
    [keyboard.kicad_pcb, keyboard.kicad_sch]
2023-01-25 Place the keys on the PCB
    [keyboard.kicad_pcb]
2023-01-25 Add an edge cut
    [keyboard.kicad_pcb]
2023-01-25 Add stabiliser
    [keyboard.kicad_pcb, keyboard.kicad_sch, keyboard.step]
2023-01-25 Make the keyboard narrower.
    [keyboard.kicad_pcb, keyboard.step]
2023-01-26 Update the PCB shape
    [keyboard.kicad_pcb]
2023-01-26 Remove the top PCB lip
    [keyboard.kicad_pcb, keyboard.step]
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2023-01-27 Add a changelog for the manufature files and add v4 files including the first prototype keyboard designs.
    [back.dxf, front.dxf, keyboard-fascia-bottom.dxf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]
2023-01-28 Change switch orientation and shrink the board
    [keyboard.kicad_pcb, keyboard.step]
2023-01-28 Update the todo list and add the nice nano to the bom
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2023-01-28 Add the Keebio symbols and footprints, and add a Pro Micro to the PCB
    [keyboard.kicad_sch]
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2023-01-28 Add the reset switch
    [keyboard.kicad_pcb, keyboard.kicad_sch]
2023-01-28 Add reset and cutout for the power switch
    [keyboard.kicad_pcb, keyboard.step]
2023-01-28 Switch the PCB back to a single top tab
    [keyboard.kicad_pcb, keyboard.step]
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2023-01-30 Add the v5 manufacture files
    [back.dxf, front.dxf, keyboard-fascia-bottom.dxf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]
2023-01-31 Add the collar to the v5 manufacture and rename changelog to readme
    [switch-collar.dxf]
2023-02-01 Add keyboard PCB dxf
    [keyboard-pcb.dxf]
2023-02-02 Move the keyboard PCB into a subdirectory
    [keyboard.kicad_pcb, keyboard.kicad_sch, keyboard.step]
2023-02-02 Revert "Add keyboard PCB dxf"
    This reverts commit 11cd0f0d0970ff13edf044c3e2837cd889cffe44.
    [keyboard-pcb.dxf]
2023-02-03 Revert "Revert "Add keyboard PCB dxf""
    This reverts commit 4a08dc427c2ede267a32dcfcff2c46b04d4ba430.
    [keyboard-pcb.dxf]
2023-02-03 Revert "Move the keyboard PCB into a subdirectory"
    This reverts commit 21bf9d4c528896e248c0893fe2d68b4e5b007bb6.
    [keyboard.kicad_pcb, keyboard.kicad_sch, keyboard.step]
2023-02-03 Add the diodes
    [keyboard.kicad_pcb, keyboard.kicad_sch]
2023-02-03 First-pass diode placement
    [keyboard.kicad_pcb, keyboard.kicad_sch]
2023-02-03 Place the spacebar diode
    [keyboard.kicad_pcb]
2023-02-03 Wire up the rows and columns in the schematic
    [keyboard.kicad_sch]
2023-02-03 Update the PCB with the wiring for the rows and columns
    [keyboard.kicad_pcb]
2023-02-04 Start to add the wiring for the keyboard
    [keyboard.dsn, keyboard.kicad_pcb, keyboard.kicad_sch]
2023-02-04 Add the power and clean up the reset button a little
    [keyboard.kicad_pcb, keyboard.kicad_sch]
2023-02-04 Tweak the keyboard layout a little for the power connector
    [keyboard.kicad_pcb]
2023-02-04 Add the connector for the power switch and the holes for the broaching nuts
    [keyboard.kicad_pcb, keyboard.kicad_sch]
2023-02-05 Adjust the placement of the nicenano to align the USB-C port.
    [keyboard.kicad_pcb, keyboard.step]
2023-02-05 Add the display adapter
    [keyboard.kicad_pcb, keyboard.kicad_sch]
2023-02-05 Clean up the silkscreen a little
    [keyboard.kicad_pcb]
2023-02-05 Clean up the silkscreen some more and add name and version
    [keyboard.kicad_pcb]
2023-02-05 Further silkscreen cleanup
    [keyboard.kicad_pcb]
2023-02-05 Route the PCB
    [keyboard.dsn, keyboard.kicad_pcb]
2023-02-05 Add the v6 manufacture with updated PCB silhouette
    [back.dxf, front.dxf, keyboard-fascia-bottom.dxf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]
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2023-02-05 Minor update
    [keyboard.kicad_pcb]
2023-02-05 Update the PCB model
    [keyboard.step]
2023-02-12 Update the manufacture files to add the keyboard mounting brackets and updated fascia and mounting plate
    [back.dxf, front.dxf, keyboard-fascia-bottom.dxf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]
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2023-02-16 Add a note on kerfing adjustments and additional step for checking the aluminium mounting plate
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2023-02-17 Update the mounting plate render and add a link to the DXF
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2023-02-17 Update the assembly and put it at the top of the keyboard section
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2023-02-21 Update the latest manufacture files (#4)
    [back.dxf, front.dxf, keyboard-fascia-bottom-kerf-adjusted-0.2.dxf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]
2023-02-24 Add keyboard mounting plate diagram
    [keyboard-mounting-plate.dxf]
2023-02-24 Add screws and nuts
    [91200A222_18-8 Stainless Steel Pan Head Slotted Screws.STEP, 93070A070_Alloy Steel Low-Profile Socket Head Screw.STEP, KF2-M2.5-ET-Zygology-3D-02-05-2023.stp]
2023-02-24 Add manufacture files
    [keyboard-fascia-bottom-kerf-adjusted-0.2.dxf, keyboard-fascia-bottom.dxf, keyboard-fascia-left-kerf-adjusted-0.2.dxf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]
2023-02-24 Remove legacy manufacture files to simplify things
    [back.dxf, front.dxf, keyboard-fascia-bottom-kerf-adjusted-0.2.dxf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]
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2024-03-25 Add the kerf-adjusted fascias
    [front.dxf, keyboard-fascia-bottom.dxf, keyboard-fascia-left.dxf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]
2024-03-25 Add the mounting brackets
    [bracket-bottom.stl, bracket-top.stl]
2026-07-19 fix: 📦 Support Zephyr 4.1 (#28)
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2026-07-19 fix: 📦 Don’t flag GitHub releases as pre-release (#31)
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2026-07-19 fix: ⌨️ Allow modifier keys on all layers (#34)
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2026-07-19 fix: 🔄 Move Bluetooth clear to Lower + F5 (#37)
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2026-07-20 fix: ⌨️ Rename keyboard to ‘Little Keyboard’ (#43)
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2026-08-13 chore(website): ⬆️ Require `jekyll-gfm-admonitions` 1.3 or above (#61)
    docs/_theme:
    - 0c7d47d fix: Require `jekyll-gfm-admonitions` 1.3 or above
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2026-08-20 docs(website): 📏 Tighten the vertical spacing (#65)
2026-08-20 chore: ⬆️ Update showcase-theme (#66)
    - 3b2b928 fix: ⬜️ Don’t round showcase and icon corners
    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
2026-08-20 docs(website): ⬜️ Don't round symbol corners (#67)
    - d672734 fix: ⬜️ Don't round symbol corners
    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
2026-08-24 docs(website): 🛟 Clean up the documentation appearance (#72)
    Catch up to the latest showcase theme with small tweaks to the
    documentation sidebar layout and photo gallery support.
    - 0ff610f fix: 🪾 Tighten documentation navigation tree
    - 06aedc6 feat: 🎞️ Add photo gallery support
    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
2026-09-03 docs(website): 💁 Add short introduction to the documentation (#86)
2026-09-04 fix: ℹ️ Generate release manifests (#87)
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2026-09-13 fix: 💎 Update dependency tzinfo to v2 (#95)
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2026-09-13 fix: 💎 Update dependency wdm to "~> 0.2.0" (#97)
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2026-09-13 fix: 💎 Update dependency jekyll to "~> 4.4.0" (#96)
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2026-10-07 ci: ⚙️ Update jdx/mise-action action to v5.1.1 (#123)
    action | minor | `v5.0.1` → `v5.1.1` |
    [`v5.1.1`](https://redirect.github.com/jdx/mise-action/releases/tag/v5.1.1):
    : GitHub token is no longer exported to later steps by default
    Source](https://redirect.github.com/jdx/mise-action/compare/v5.1.0...v5.1.1)
    mise-acti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
2026-10-14 ci: ⚙️ Update dependency jdx/mise to v2026.10.10 (#129)
    `2026.10.9` → `2026.10.10` |
    [`v2026.10.10`](https://redirect.github.com/jdx/mise/releases/tag/v2026.10.10):
    : Task skip_if, snap and COPR in bootstrap, and dotfiles pull fixes
    Source](https://redirect.github.com/jdx/mise/compare/vfox-v2026.10.9...vfox-v2026.10.10)
    Tasks can now sk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
2026-10-17 ci: ⚙️ Update dependency jdx/mise to v2026.10.13 (#134)
    `2026.10.12` → `2026.10.13` |
    [`v2026.10.13`](https://redirect.github.com/jdx/mise/releases/tag/v2026.10.13):
    : Untrusted project configs can no longer change settings
    Source](https://redirect.github.com/jdx/mise/compare/vfox-v2026.10.12...vfox-v2026.10.13)
    mise now ignores `[setti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
2026-10-22 build: 🔨 Update ruby to v4.0.8 (#141)
    | [ruby](https://www.ruby-lang.org)
    ([source](https://redirect.github.com/ruby/ruby)) | tools | patch |
    `4.0.7` → `4.0.8` |
    <summary>ruby/ruby (ruby)</summary>
    [`v4.0.8`](https://redirect.github.com/ruby/ruby/releases/tag/v4.0.8):
    4.0.8
    Source](https://redirect.github.com/ruby/ruby/compare/v4.0.7...v4.0.8)
    ##### What's Changed
    - [Bug #&#8203;22311: Build crashes on macOS 26 with the macOS 27 SDK
    be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
2026-10-24 ci: ⚙️ Update jdx/mise-action action to v5.2.3 (#144)
    action | patch | `v5.2.2` → `v5.2.3` |
    [`v5.2.3`](https://redirect.github.com/jdx/mise-action/releases/tag/v5.2.3):
    : Faster cache key computation in large workspaces
    Source](https://redirect.github.com/jdx/mise-action/compare/v5.2.2...v5.2.3)
    The cache key no longer comes from sear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
2026-11-03 ci: ⚙️ Update jdx/mise-action action to v5.2.6 (#157)
    action | patch | `v5.2.5` → `v5.2.6` |
    [`v5.2.6`](https://redirect.github.com/jdx/mise-action/releases/tag/v5.2.6):
    : Fix step hanging after a failed cache restore
    Source](https://redirect.github.com/jdx/mise-action/compare/v5.2.5...v5.2.6)
    The action now exits as soon as its work i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
2026-11-06 ci: ⚙️ Update jdx/mise-action action to v5.2.7 (#162)
    action | patch | `v5.2.6` → `v5.2.7` |
    [`v5.2.7`](https://redirect.github.com/jdx/mise-action/releases/tag/v5.2.7):
    : Retry failed mise downloads with backoff and show the HTTP status
    Source](https://redirect.github.com/jdx/mise-action/compare/v5.2.6...v5.2.7)
    When the action can't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
2026-11-12 ci: ⚙️ Update dependency jdx/mise to v2026.11.7 (#167)
    `2026.11.6` → `2026.11.7` |
    [`v2026.11.7`](https://redirect.github.com/jdx/mise/releases/tag/v2026.11.7):
    : Shorter shim errors, task run history in JSON, and dotfiles safety
    fixes
    Source](https://redirect.github.com/jdx/mise/compare/vfox-v2026.11.6...vfox-v2026.11.7)
    When no config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
2026-11-13 ci: ⚙️ Update jdx/mise-action action to v5.2.8 (#168)
    action | patch | `v5.2.7` → `v5.2.8` |
    [`v5.2.8`](https://redirect.github.com/jdx/mise-action/releases/tag/v5.2.8):
    : Fix mise install on Windows when MISE_DATA_DIR is on another drive
    Source](https://redirect.github.com/jdx/mise-action/compare/v5.2.7...v5.2.8)
    On Windows, the actio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
